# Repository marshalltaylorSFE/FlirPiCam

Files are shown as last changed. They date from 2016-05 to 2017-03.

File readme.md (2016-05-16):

Flir Pi Cam
====================================

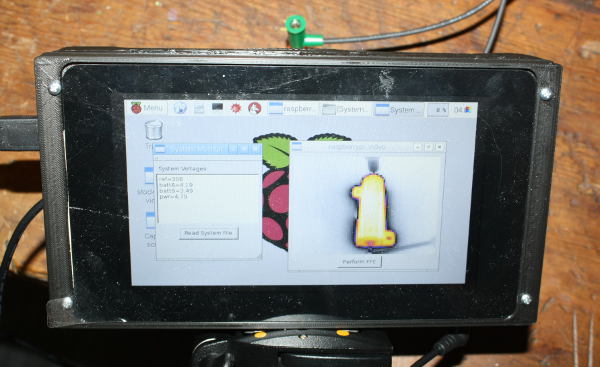
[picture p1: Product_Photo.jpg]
Product photo.


This is an open source design for a FLiR thermal camera built on the raspberry Pi.

Features
----------------

* Flir Lepton module
* Raspberry Pi 2
* 7 inch touchscreen
* ~1 hour battery life
* Rechargeable
* Battery monitoring into linux
* Button interface for capturing screenshots, mounting and unmounting usb
* Buttons can trigger custom shell scripts which can be edited from the OS

Linux software
-----------------

* Raspbian
* Flir Video monitor demo for the Lepton module
* Custom qt4 application for system monitor
* scrot screen capture

Extra Linux software
-----------------

* capture for capturing usb video streams
* ffmpeg for compression

System Firmware
-------------------

* Operates as class compliant keyboard for some functions (login screepting).  TODO: auto login
* Operates as USB serial TTY for running screen capture/custom scripts
* Button hold features implemented, can be used for alternate scripts of sudoing the scripts

System Hardware
-----------------

* 2 powercells
* 2 lipo batteries
* Physical battery disconnect switch
* MCU connected by USB
* Diode or-ing of power rails, priority to source
* 4 buttons
* 1 LED
* analog channels calibrated by TLV431 bandgap ref
* Measures battery voltages and system rail

This is released under the [Creative Commons ShareAlike 4.0 International](https://creativecommons.org/licenses/by-sa/4.0/) license. 

Please consider contributing back to this library or others to help the open-source hardware community continue to thrive and grow!

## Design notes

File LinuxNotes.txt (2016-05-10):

ls -l /dev/ttyUSB0
and you will see something like "crw-rw----T 1 root dialout ..."

(unused)Teensy rules for something?
/etc/udev/rules.d/49-teensy.rules

Create /etc/init/ttyUSB0.conf and paste the following into it:
# ttyUSB0 - getty on USB serial port
#
# This service maintains a getty on ttyUSB0 from the point the system is
# started until it is shut down again.

start on stopped rc RUNLEVEL=[2345]
stop on runlevel [!2345]

respawn
exec /sbin/getty -L 115200 ttyUSB0 vt102

Edit /etc/inittab

something like:
T0:23:respawn:/sbin/getty -L ttyS0 115200 vt100

...then...

sudo /sbin/telinit q

Bash commands:

Redirection:
> is output redirection symbol.
>> is append output redirection symbol.

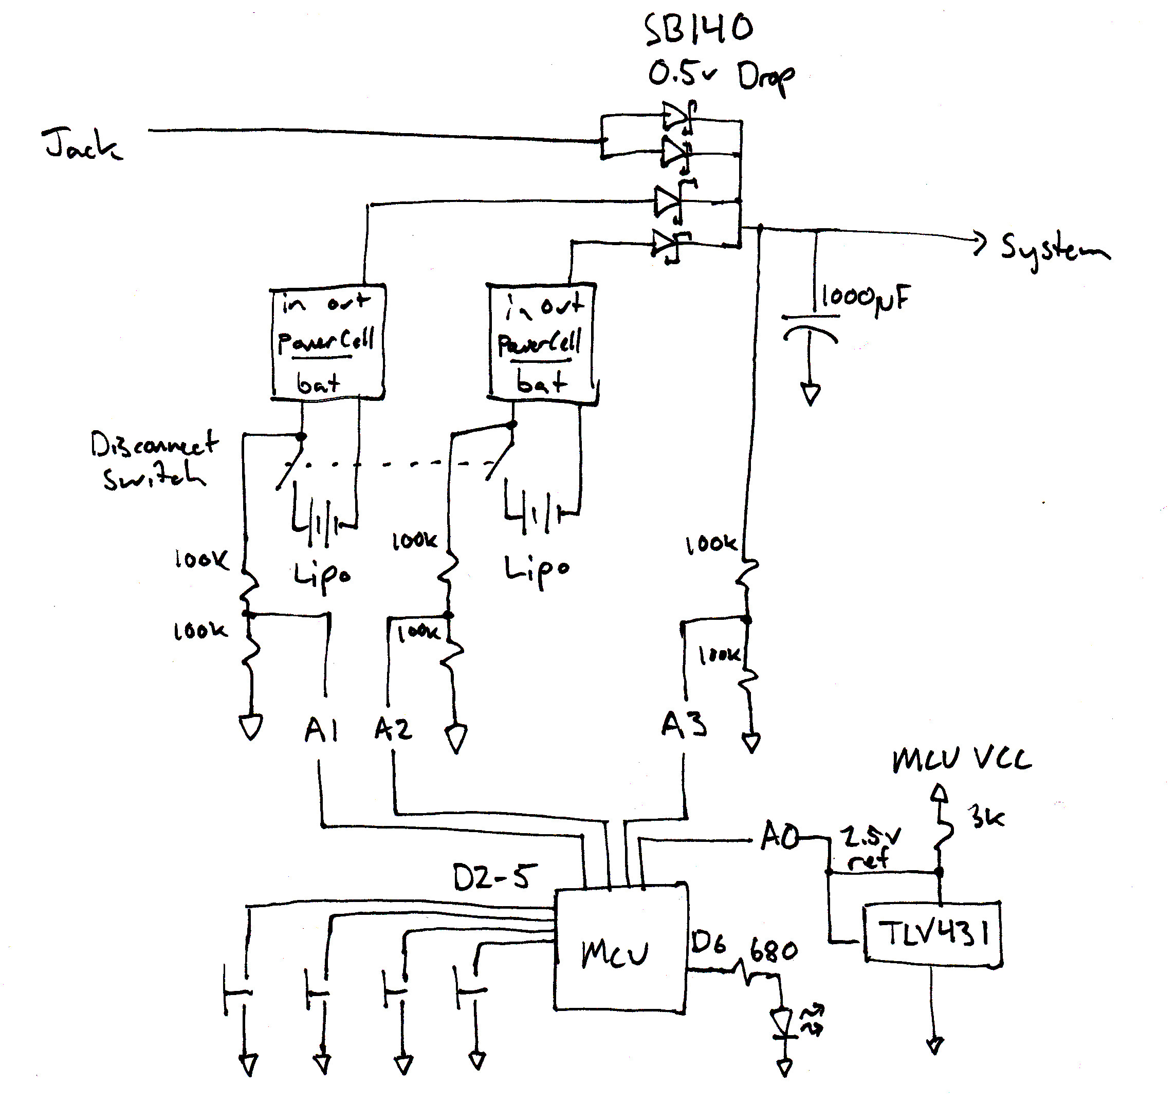
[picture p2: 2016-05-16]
SystemControlHardware/schematic.jpg

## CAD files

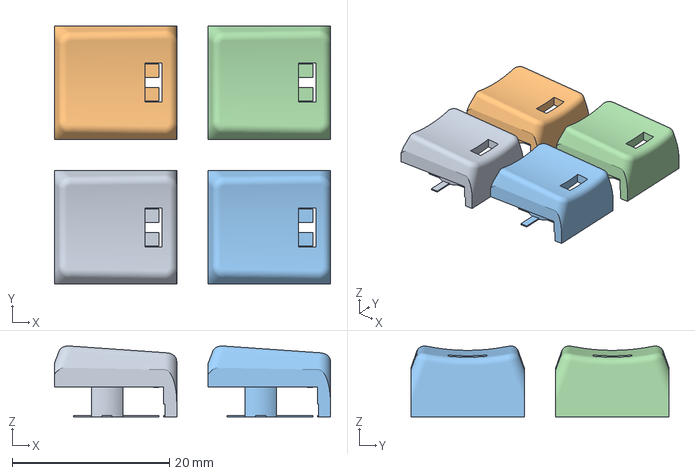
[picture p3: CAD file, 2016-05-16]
Case/Keycaps/4upraftsupportTruncatedButtons.amf
35.1 x 32.9 x 9.04 mm

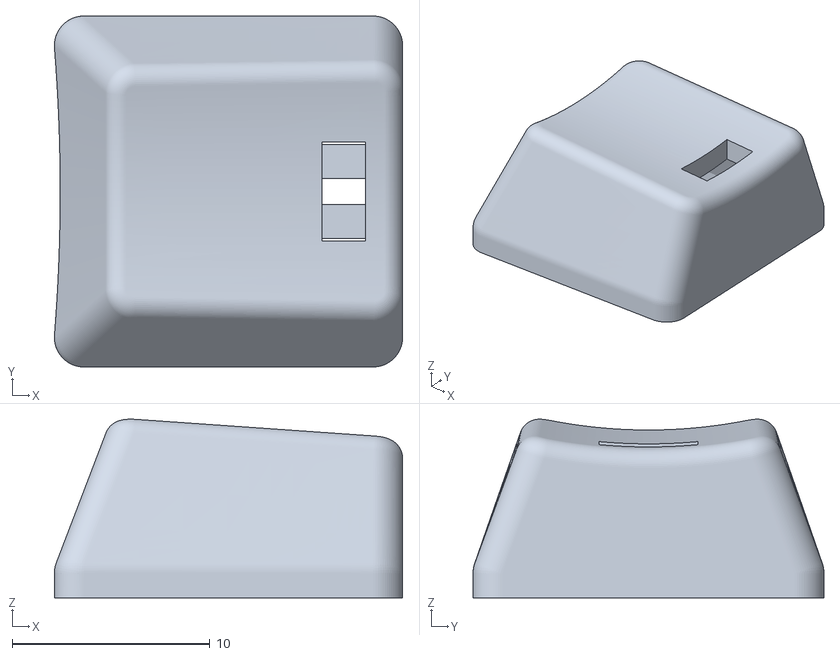
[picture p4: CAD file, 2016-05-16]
Case/Keycaps/KeycapWindowed.stl
17.6 x 17.8 x 9.04

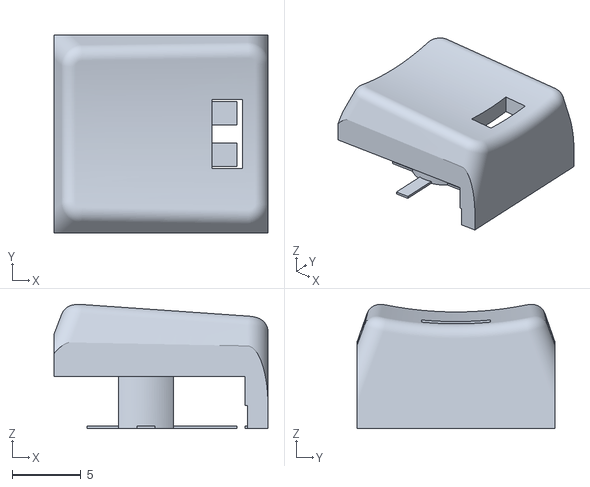
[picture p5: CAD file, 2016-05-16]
Case/Keycaps/kecapWindowedTruncatedOutput.stl
15.6 x 14.4 x 9.04

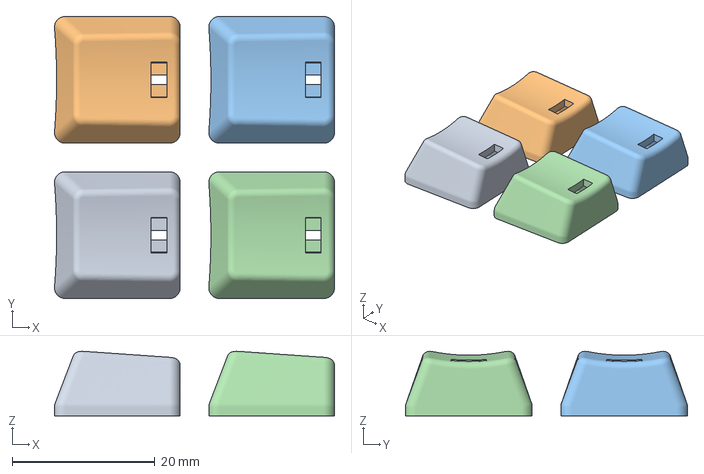
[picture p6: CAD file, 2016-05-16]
Case/Keycaps/4upraftsupport.amf
39.2 x 39.5 x 9.04 mm

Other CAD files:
Case/Keycaps/keyOutput.stl
Case/Body_Bezel/002BackStandoffs.blend
Case/Body_Bezel/004bezeloutput.blend
Case/Body_Bezel/007rebuildingall.blend
Case/Body_Bezel/009_resave.blend
Case/Body_Bezel/010_Front not holed.blend
Case/Body_Bezel/010_justback.blend
Case/Body_Bezel/master.blend
Case/Keycaps/KeycapWindowed.blend
Case/Keycaps/kecapWindowedTruncated.blend
Case/Source_Parts/1420BUscale.blend
Case/Source_Parts/4-40_looseBUscale.blend
Case/Source_Parts/4-40_standoffBUscale.blend
Case/Source_Parts/4-40_tightBUscale.blend
Case/Source_Parts/batteryBUscale.blend
Case/Source_Parts/buttonBUscale.blend
Case/Source_Parts/cherryBUscale.blend
Case/Source_Parts/flirmoduleBUscale.blend
Case/Source_Parts/microb.blend
Case/Source_Parts/piBUscale.blend
Case/Source_Parts/promicroBUscale.blend
Case/Source_Parts/pwrcellBUscale.blend
Case/Source_Parts/screenBUscale.blend
Case/Source_Parts/standoffback.blend
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

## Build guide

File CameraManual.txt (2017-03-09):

Buttons:  USB ports<-[1, 2, 3, 4]

Button 1:
Use to enter username
Use to enter password
Use to enter startx
Use to start system monitor back-end

Button 2:
Take picture (Saves to home)

Button 3:
Mount USB device

Button 4:
Unmount USB device

Booting procedure
1.  Wait for prompt
2.  Push button 1
3.  Wait for prompt (and flashing button)
4.  Push button 1
5.  Wait for prompt (and flashing button)
6.  Push button 1
7.  Wait for WDM to load
8.  Push button 1 to start system monitor (LED should go solid)
9.  Load the "Stock Video Viewer" and "System Monitor", arrange on screen

Do FFC with flat temp field
Click "Read System File" to get voltages
Push button 2 to take picture

Battery switch:

  Left: Batteries disconnected
  Right: Batteries connected

If the system monitor reports values like 4.2 on both batteries, they are charged or charging and connected
If the values are in the lower range, they are not connected, or the wall adapter is not connected.

DO NOT LEAVE SWITCH IN RIGHT POSITION.  Alaways disconnect cells between use.

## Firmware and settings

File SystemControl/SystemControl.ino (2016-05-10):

#include <TimerOne.h>

//HOW TO OPERATE
//  Make TimerClass objects for each thing that needs periodic service
//  pass the interval of the period in ticks
//
//  Set MAXINTERVAL to rollover rate
//  Set MAXTIMER to the max foreseen interval of any timer.
//  MAXTIMER + MAXINTERVAL = max countable value.

//NOTICE:
//  The timerModule32 only works on teensy / fast processors.  It works the same
//  but keeps track of everything in us counts.


//Not used by this sketch but dependant on one 
#include "Wire.h"
#include "Panel.h"
#include "stdint.h"

#include "timerModule32.h"

#define REFPIN A0
#define BATTAPIN A1
#define BATTBPIN A2
#define SYSTEMRAILPIN A3


//Globals
uint32_t MAXTIMER = 60000000;
uint32_t MAXINTERVAL = 2000000;

uint8_t ledToggleState = 0;
uint8_t ledToggleFastState = 0;

//**Copy to make a new timer******************//  
//        TimerClass32 usTimerA( 20000 ); //20 ms
//
//Note on TimerClass-
//Change with usTimerA.setInterval( <the new interval> );
TimerClass32 panelUpdateTimer(10000);
TimerClass32 debounceTimer(5000);
TimerClass32 ledToggleTimer( 333000 );
TimerClass32 ledToggleFastTimer( 100000 );

TimerClass32 debugTimer(5000000);

//**Panel State Machine***********************//
#include "SystemPanel.h"
SystemPanel embKeys;

uint32_t usTicks = 0;

//  The lock works like this:
//
//    When the interrupt fires, the lock is removed.  Now
//    the main free-wheeling loop can update the change to
//    the timerModules.  Once complete, the lock is replaced
//    so that it can't update more than once per firing
//    of the interrupt

uint8_t usTicksLocked = 1; //start locked out

void setup()
{
	Serial.begin(115200);

  	//Init panel.h stuff
	embKeys.init();
	
	// initialize timer
	Timer1.initialize(25);
	Timer1.attachInterrupt(serviceUS); // blinkLED to run every 0.001 seconds
	
	//Go to fresh state
	embKeys.reset();
	
	//Update the panel
	embKeys.update();
  
}

void loop()
{
	if( Serial.available() )
	{
		Serial.read();
		embKeys.serialActivityFlag.setFlag();
		delay(10);
	}
	
	//Update the timers, but only once per interrupt
	if( usTicksLocked == 0 )
	{
		//**Copy to make a new timer******************//  
		//msTimerA.update(usTicks);

		//Panel timers
		ledToggleTimer.update(usTicks);
		ledToggleFastTimer.update(usTicks);
		panelUpdateTimer.update(usTicks);
		debounceTimer.update(usTicks);

		debugTimer.update(usTicks);
		
		//Done?  Lock it back up
		usTicksLocked = 1;
	}  //The ISR will unlock.

	//**Copy to make a new timer******************//  
	//if(usTimerA.flagStatus() == PENDING)
	//{
	//	//User code
	//}
	
	//**Debounce timer****************************//  
	if(debounceTimer.flagStatus() == PENDING)
	{
		embKeys.timersMIncrement(5);
	
	}
		
	//**Process the panel and state machine***********//  
	if(panelUpdateTimer.flagStatus() == PENDING)
	{
		//Provide inputs

		//Tick the machine
		embKeys.processMachine();
		
		//Deal with outputs 
		//  Form: if( myFlagName.resetTapHeadFlag.serviceRisingEdge() )...
		
	}
	//**Fast LED toggling of the panel class***********//  
	if(ledToggleFastTimer.flagStatus() == PENDING)
	{
		embKeys.toggleFastFlasherState();
		
	}

	//**LED toggling of the panel class***********//  
	if(ledToggleTimer.flagStatus() == PENDING)
	{
		embKeys.toggleFlasherState();
		
	}
	//**Debug timer*******************************//  
	if(debugTimer.flagStatus() == PENDING)
	{
		//uint32_t tempRef = analogRead(REFPIN);
		//Serial.println("**************************Debug Service**************************");
		//Serial.print("Current state: ");
		//Serial.println(embKeys.getState());
		//
		//Serial.print("Ref value: ");
		//Serial.println(tempRef, HEX);
		//
		//Serial.print("A voltage: ");
		//Serial.println(((float)analogRead(BATTAPIN) * 5)/tempRef);
		//
		//Serial.print("B voltage: ");
		//Serial.println(((float)analogRead(BATTBPIN) * 5)/tempRef);
		//
		//Serial.print("System soltage: ");
		//Serial.println(((float)analogRead(SYSTEMRAILPIN) * 5)/tempRef);
		
		if(embKeys.writeFileFlag.getFlag() )
		{
			uint32_t tempRef = analogRead(REFPIN);
			
			Serial.print("echo ");
			Serial.print("ref=");
			Serial.print(tempRef, HEX);
			Serial.print(" > system_status.log\r");
			delay(100);
			while( Serial.available() )
			{
				Serial.read();
			}		
			
			Serial.print("echo ");
			Serial.print("battA=");
			Serial.print(((float)analogRead(BATTAPIN) * 5)/tempRef);
			Serial.print(" >> system_status.log\r");
			delay(100);
			while( Serial.available() )
			{
				Serial.read();
			}		
			
			Serial.print("echo ");
			Serial.print("battB=");
			Serial.print(((float)analogRead(BATTBPIN) * 5)/tempRef);
			Serial.print(" >> system_status.log\r");
			delay(100);
			while( Serial.available() )
			{
				Serial.read();
			}		
			
			Serial.print("echo ");
			Serial.print("pwr=");
			Serial.print(((float)analogRead(SYSTEMRAILPIN) * 5)/tempRef);
			Serial.print(" >> system_status.log\r");
		}
	
	}
}

void serviceUS(void)
{
  uint32_t returnVar = 0;
  if(usTicks >= ( MAXTIMER + MAXINTERVAL ))
  {
    returnVar = usTicks - MAXTIMER;

  }
  else
  {
    returnVar = usTicks + 25;
  }
  usTicks = returnVar;
  usTicksLocked = 0;  //unlock
}

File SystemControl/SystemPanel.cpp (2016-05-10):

//**SystemPanel*******************************//
#include "SystemPanel.h"
//#include "PanelComponents.h"
#include "Panel.h"
#include "Arduino.h"
#include "flagMessaging.h"

//Redefined here...
#define REFPIN A0
#define BATTAPIN A1
#define BATTBPIN A2
#define SYSTEMRAILPIN A3

SystemPanel::SystemPanel( void )
{
	state = PInit;
	bootState = 0;
	altFunctionHeld = 0;
}

void SystemPanel::reset( void )
{
	//Set explicit states
	//Set all LED off
	aLed.setState(LEDFLASHINGFAST);
	
	update();
	
}

//---------------------------------------------------------------------------//
//
//  To process the machine,
//    take the inputs from the system
//    process human interaction hard-codes
//    process the state machine
//    clean up and post output data
//
//---------------------------------------------------------------------------//
void SystemPanel::processMachine( void )
{
	//Do small machines

	//Do main machine
	tickStateMachine();
	
	//Set outputs for select objects
	if(serialActivityFlag.getFlag())
	{
		aLed.setState(LEDOFF);
		serialActivityFlag.clearFlag();
	}
	else
	{
		aLed.setState(ALEDSTATE);
	}
	//Update the hardware
	update();
}

void SystemPanel::tickStateMachine()
{
	//***** PROCESS THE LOGIC *****//
	//Now do the states.
	PStates nextState = state;
	switch( state )
	{
	case PInit:
		nextState = PIdle;
		ALEDSTATE = LEDFLASHING;
		break;
	case PIdle:
		//Can't be running, if button pressed move on
		if( aButton.serviceRisingEdge() )
		{
			Keyboard.println("pi");
			nextState = PBootA;
		}
		break;
	case PBootA:
		if( aButton.serviceRisingEdge() )
		{
			Keyboard.println("raspberry");
			delay(300);
			
			//Log in serial
			while( Serial.available() )
			{
				Serial.read();
			}
			Serial.print("pi\r");
			delay(100);
			while( Serial.available() )
			{
				Serial.read();
			}
			Serial.print("raspberry\r");
			delay(100);
			while( Serial.available() )
			{
				Serial.read();
			}		
			Serial.print("touch system_status.log\r");
			delay(100);
			while( Serial.available() )
			{
				Serial.read();
			}		
			nextState = PBootB;
		}
		break;
	case PBootB:
		if( aButton.serviceRisingEdge() )
		{
			Keyboard.println("startx");
			nextState = PBootC;
		}
		break;
	case PBootC:
		if( aButton.serviceRisingEdge() )
		{
			//run log
			writeFileFlag.setFlag();
			ALEDSTATE = LEDON;
			nextState = PRunning;
		}
		break;
	case PRunning:
		if( aButton.serviceRisingEdge() )
		{
			if( altFunctionHeld )
			{
				//Alt function, reset keyboard
				nextState = PInit;
			}
			else
			{
				Serial.print("sh buttonA.sh &\r");
			}
		}
		if( bButton.serviceRisingEdge() )
		{
			if( altFunctionHeld )
			{
				//Alt function, run with sudo
				Serial.print("sudo sh buttonB.sh &\r");
			}
			else
			{
				Serial.print("sh buttonB.sh &\r");
			}
		}
		if( cButton.serviceRisingEdge() )
		{
			if( altFunctionHeld )
			{
				//Alt function, run with sudo
				Serial.print("sudo sh buttonC.sh &\r");
			}
			else
			{
				Serial.print("sh buttonC.sh &\r");
			}
		}
		if( dButton.serviceRisingEdge() )
		{
			Serial.print("sudo ./buttonD.sh &\r");
		}
		if( dButton.serviceHoldRisingEdge() )
		{
			altFunctionHeld = 1;
		}
		if( dButton.serviceFallingEdge() )
		{
			altFunctionHeld = 0;
		}

		break;
	default:
		nextState = PInit;
		break;
	}
	state = nextState;

}

void SystemPanel::timersMIncrement( uint8_t inputValue )
{
	aButton.buttonDebounceTimeKeeper.mIncrement(inputValue);
	bButton.buttonDebounceTimeKeeper.mIncrement(inputValue);
	cButton.buttonDebounceTimeKeeper.mIncrement(inputValue);
	dButton.buttonDebounceTimeKeeper.mIncrement(inputValue);

}

uint8_t SystemPanel::getState( void )
{
	return state;
}

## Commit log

2016-05-08 TeensyLC timing layer
2016-05-10 added keycap model
    [KeycapWindowed.blend, KeycapWindowed.stl, keyOutput.stl]
2016-05-16 added some files
    [4upraftsupport.amf, 4upraftsupportTruncatedButtons.amf, KeycapWindowed.blend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]
2016-05-16 added in more models and docu
    [002BackStandoffs.blend, 004bezeloutput.blend, 007rebuildingall.blend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]
2016-05-16 added hardware schematic
